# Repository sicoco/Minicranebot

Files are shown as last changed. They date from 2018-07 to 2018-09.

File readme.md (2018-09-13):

# MiniCraneBot

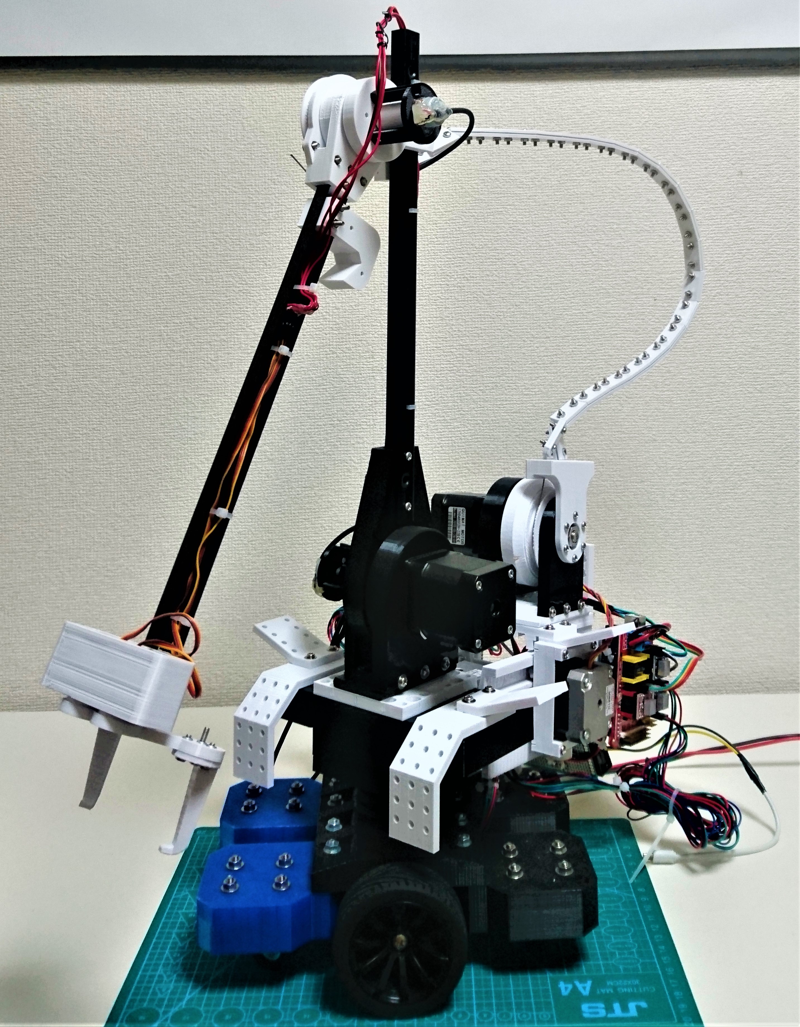
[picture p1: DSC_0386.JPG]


- basically a small mobile wheel-based platform with lightweight long robotic arm that can move around and pick things from far away without falling over.

- made most parts with 3d printer, including high gear ratio gearbox

- in order to reduce the time on prototyping and 3d printing, designed the robot's body in LEGO-ish style

- robot has 2WD and 4 caster wheel mobile platform, a 3dof planar robotic arm, 2 dof gripper, 1 dof adjustable counterweight

- able to pick about 100g at gripper and about 500g at elbow

- robot weight about 4kg because it is powered from switching power supply outside its body

[Youtube](https://www.youtube.com/watch?v=HbvBk9CqUA4)

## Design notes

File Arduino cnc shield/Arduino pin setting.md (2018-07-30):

# Arm Controller Arduino pin setting
|Arduino pin|CNC Shield V3 port Name|Connect to|Mode|
|--|--|--|--|
|D0|TX|RPi Serial|UART TX|
|D1|RX|RPi Serial|UART RX|
|D2|X-STEP|shoulder step|Accelstepper step|
|D3|Y-STEP|elbow step|Accelstepper step|
|D4|Z-STEP|waist step|Accepstepper step|
|D5|X-DIR|shoulder dir|Accelstepper dir|
|D6|Y-DIR|elbow dir|Accelstepper dir|
|D7|Z-DIR|waist dir|Accelstepper dir|
|D8|EN|All stepper driver's EN pin|Accelstepper enable|
|D9|X-Endstop|Gripper servo L|PWM|
|D10|Y-Endstop|Gripper servo R|PWM|
|D11|Z-Endstop|counterweight endstop|GPIO input|
|D12|SpnEn|counterweight step(also connects to another CNC shield's A-axis step)|Accelstepper step|
|D13|SpnDir|counterweight dir(also connects to another CNC shield's A-axis dir)|Accelstepper dir|
|A0|Abort|elbow potentiometer|ADC|
|A1|Home|shoulder potentiometer|ADC|
|A2|Resume|||
|A3|CoolEn|||
|A4|SDA|MPU6050 I2C|I2C SDA|
|A5|SCL|MPU6050 I2C|I2C SCL|

E-stop is reset button

Used libraries:
Metro: speed(25ms) and position(100ms) control
MsTimer2: get MPU6050 and potentiometer data and do some filtering to get angles updated(20ms)
Accelstepper: control all stepping motors
MPU6050_tockn: MPU605 driver
Wire: I2C library

3，5，6，9，10，11 pin have PWM function

# Car Controller Arduino pin setting
|Arduino pin|CNC Shield V3 port Name|Connect to|Mode|
|--|--|--|--|
|D0|TX|RPi Serial|UART TX|
|D1|RX|RPi Serial|UART RX|
|D2|X-STEP|Left wheel step|Accelstepper step|
|D3|Y-STEP|Right wheel step|Accelstepper step|
|D4|Z-STEP|||
|D5|X-DIR|Left wheel dir|Accelstepper dir|
|D6|Y-DIR|Right wheel dir|Accelstepper dir|
|D7|Z-DIR|||
|D8|EN|All stepper driver's EN pin(Also controls A-Axis driver's EN pin)|Accelstepper enable|
|D9|X-Endstop|||
|D10|Y-Endstop|||
|D11|Z-Endstop|||
|D12|SpnEn|should not connect to A-Axis as A-Axis driver is controlled by Arm controller Arduino now||
|D13|SpnDir|should not connect to A-Axis as A-Axis driver is controlled by Arm controller Arduino now||
|A0|Abort|||
|A1|Home|||
|A2|Resume|||
|A3|CoolEn|||
|A4|SDA|MPU6050 I2C(hopefully, if wiring can be solved)|I2C SDA|
|A5|SCL|MPU6050 I2C(hopefully, if wiring can be solved)|I2C SCL|

## Problems right now

 1. Servo are in failure: possibly overdriven too much? change new one. First print a new twin servo holder. fixed
 2. Add glue gun on gripper to increase friction. fixed
 3. Is Cooling enough? 
 4. Endstop need to get closer a little to the counterweight. fixed
 5. Why counterweight is not moving in initialization? Using runSpeed wrongly?  fixed
 6. Connect servo L and R correctly 
 7. Waist timing belt getting loose
 8. Cable entangling between car and arm. Make waist a little taller. fixed
 9. Waist plate is bending due to heavy counterweight. Make thicker waist plate.　fixed
 10. Why MPU6050_tockn not working properly? Check thoroughly.  fixed
 11. Complete feedback control on arm. fixed
 12. Elbow motor gearbox may have some problem, high friction
 13. tuning sensor offsets and servo angle offset parameters
 14. tuning Kp and error width
 15. add tensioner on waist yaw timing belt, too loose now.

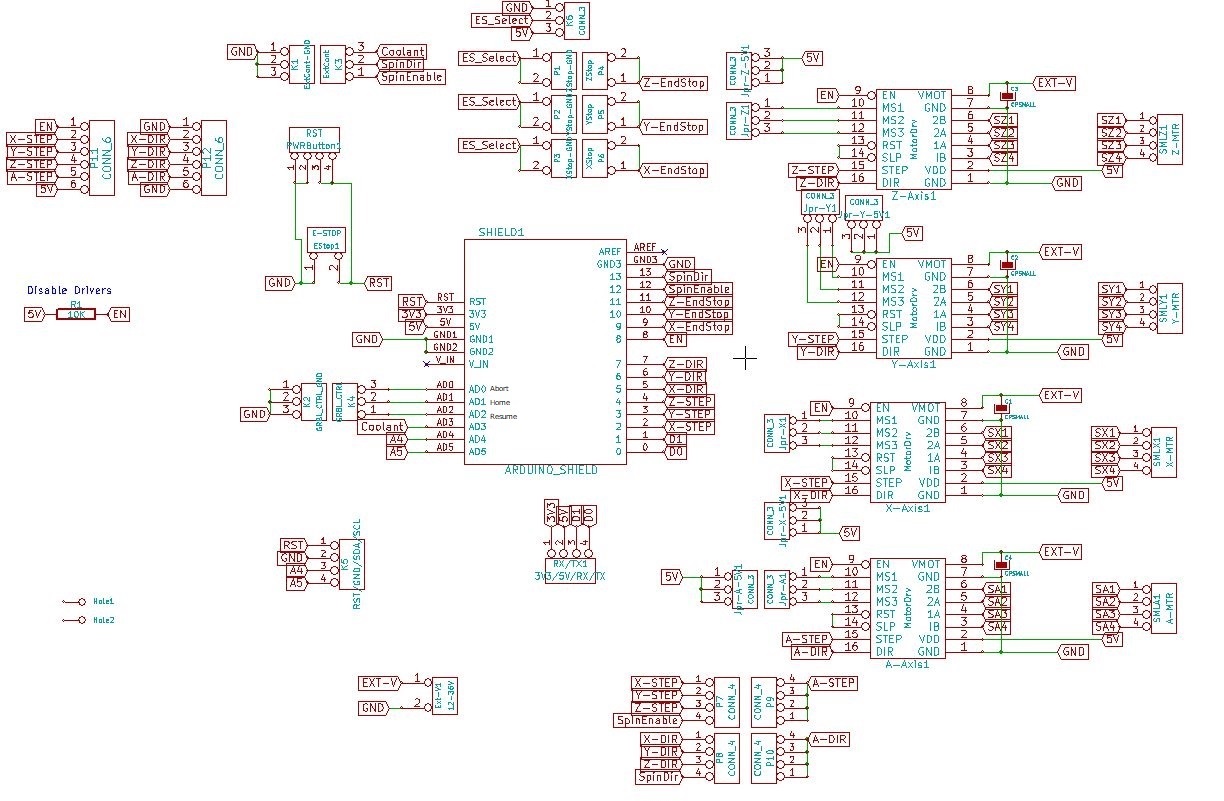
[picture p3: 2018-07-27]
Arduino cnc shield/Arduino-CNC-Shield-Scematics-V3.XX_.jpg

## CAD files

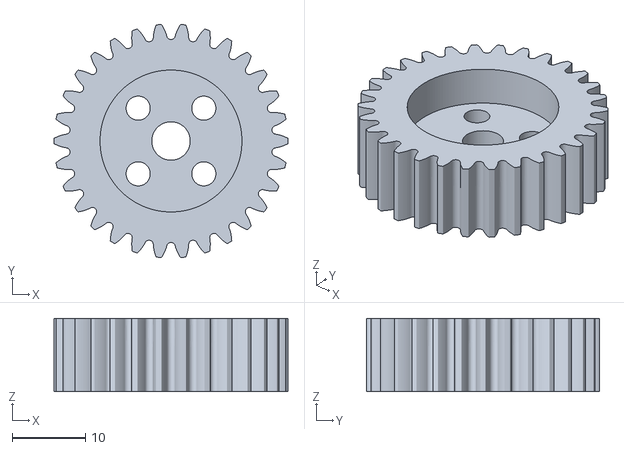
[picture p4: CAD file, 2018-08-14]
stl/30T M1 sun gear with shaft hub hole v2.stl
32.0 x 31.9 x 10.0

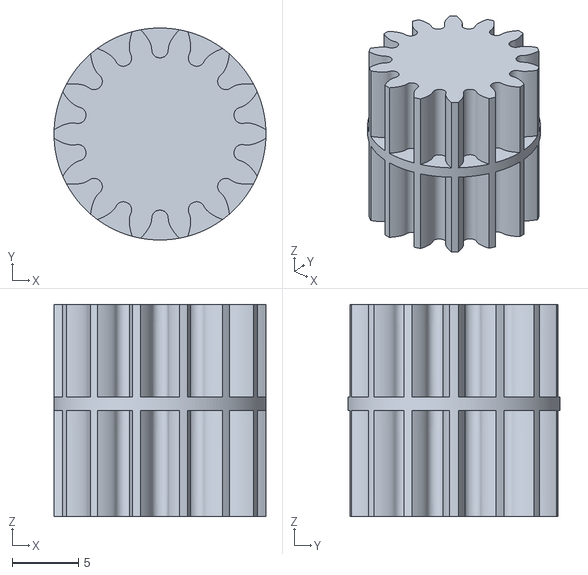
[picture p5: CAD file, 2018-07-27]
stl/planetary gear mock print at home 20180618 over night/14T planet.stl
16.0 x 16.0 x 16.0

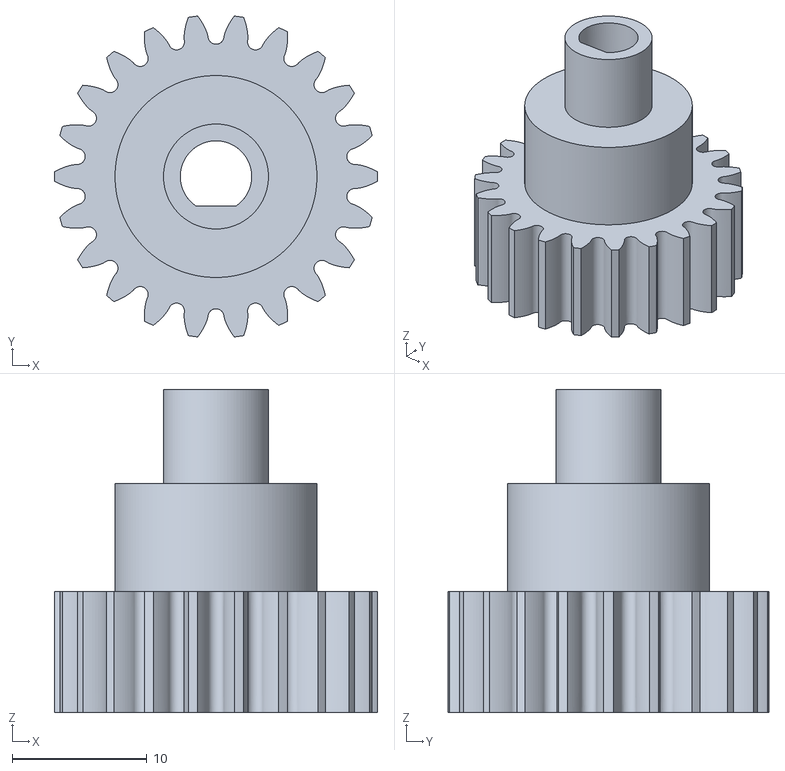
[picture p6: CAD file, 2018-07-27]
stl/planetary gearbox print at home @20180619 morning/Spur Gear (22 teeth).stl
24.0 x 23.8 x 24.0

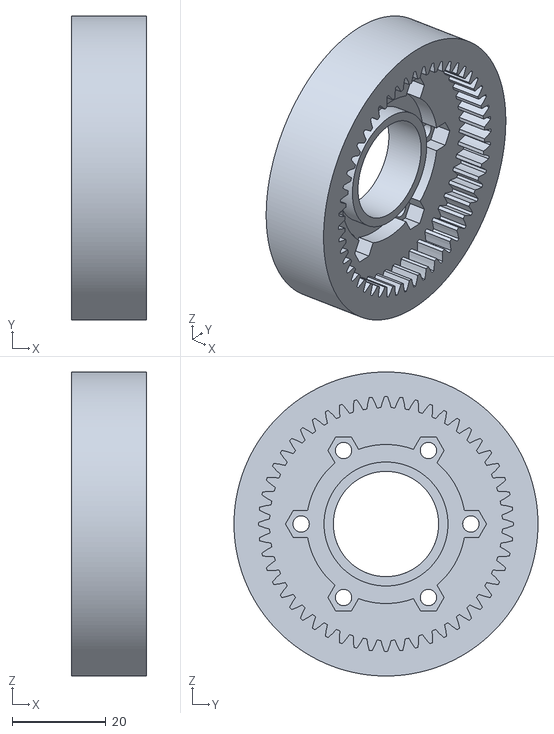
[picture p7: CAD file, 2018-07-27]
stl/Planetary gearbox print at lab 20180619/_HPC - ZIN1-52 (c).stl
16.0 x 65.0 x 65.0

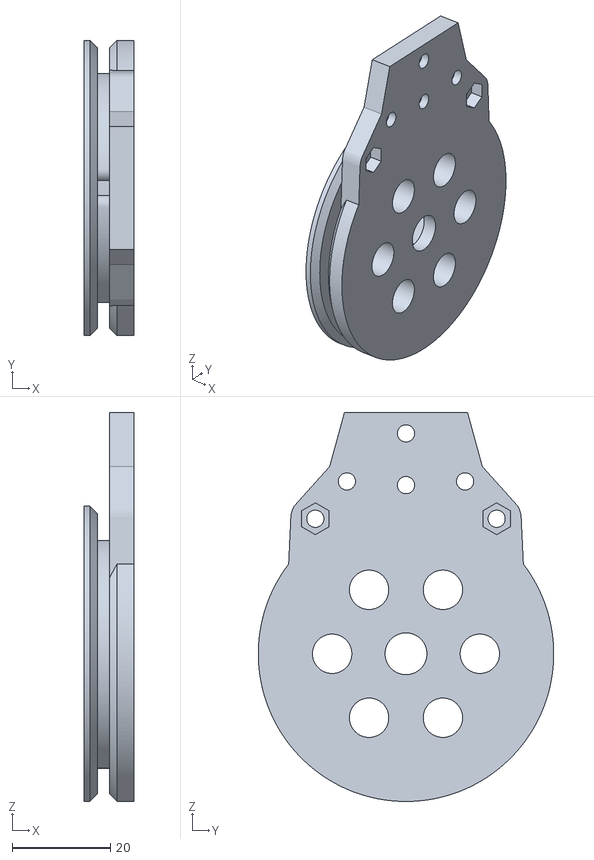
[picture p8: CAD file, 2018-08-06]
stl/bowden spool 50mm with arm v17.stl
10.2 x 60.0 x 79.0

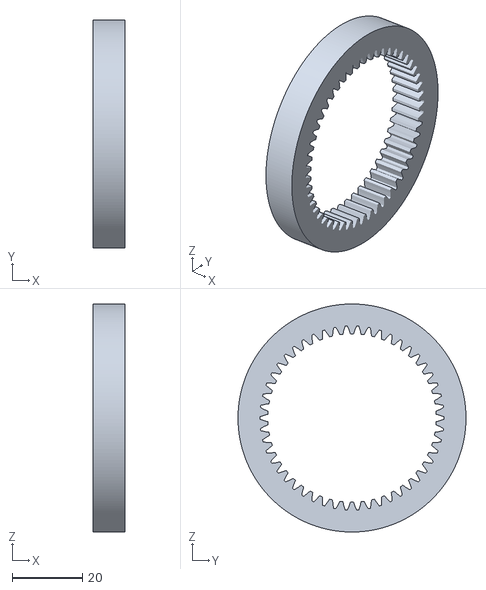
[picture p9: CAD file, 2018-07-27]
stl/planetary gear mock print at home 20180618 over night/50T internal.stl
9.00 x 65.0 x 65.0

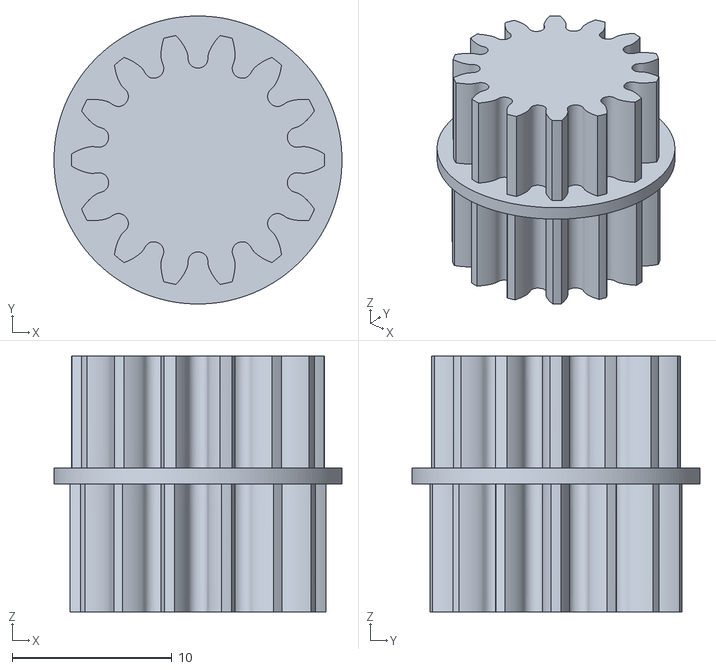
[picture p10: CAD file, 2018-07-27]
stl/planetary gearbox print at home @20180619 morning/Spur Gear (14 teeth).stl
18.0 x 18.0 x 16.0

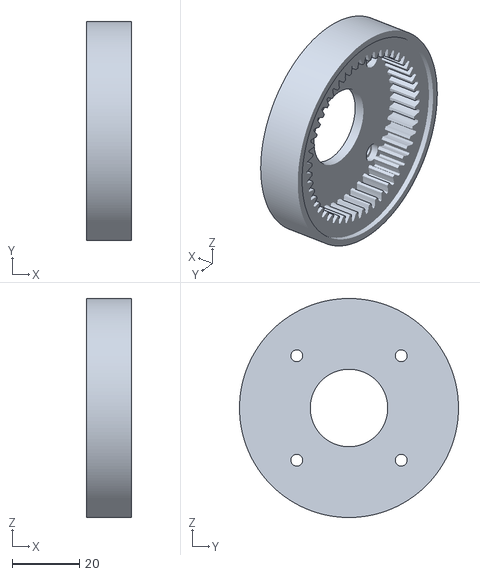
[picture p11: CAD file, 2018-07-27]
stl/Planetary gearbox print at lab 20180619/_HPC - ZIN1-50 (c).stl
13.5 x 65.0 x 65.0

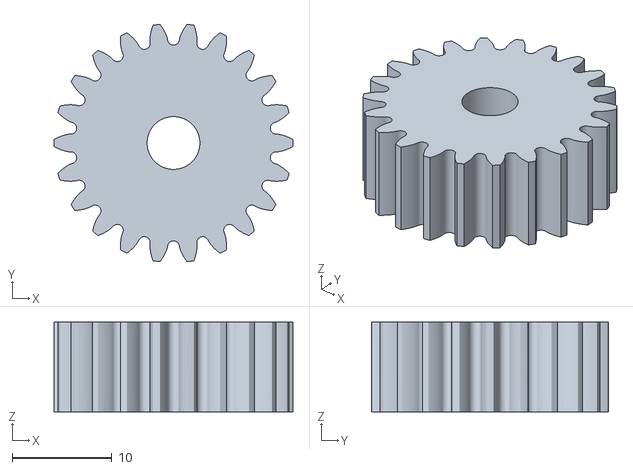
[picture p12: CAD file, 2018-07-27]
stl/planetary gear mock print at home 20180618 over night/22T sun.stl
24.0 x 23.8 x 9.00

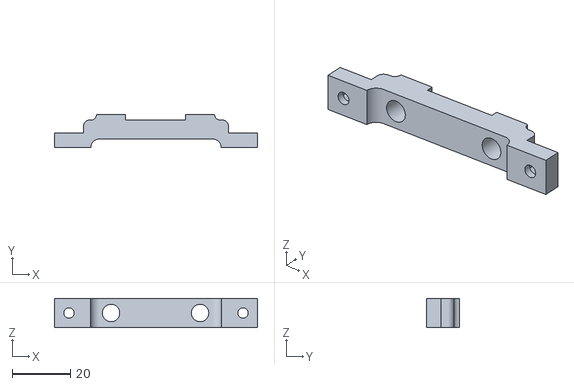
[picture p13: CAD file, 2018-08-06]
stl/tensioner plate v1.stl
70.0 x 11.5 x 10.0

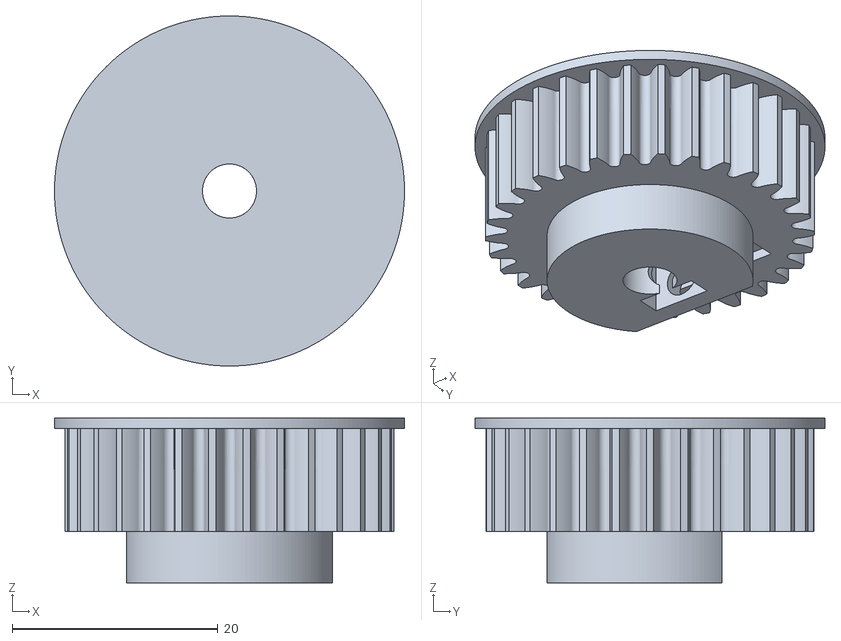
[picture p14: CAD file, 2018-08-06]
stl/30T M1 sun gear v4.stl
34.0 x 34.0 x 16.0

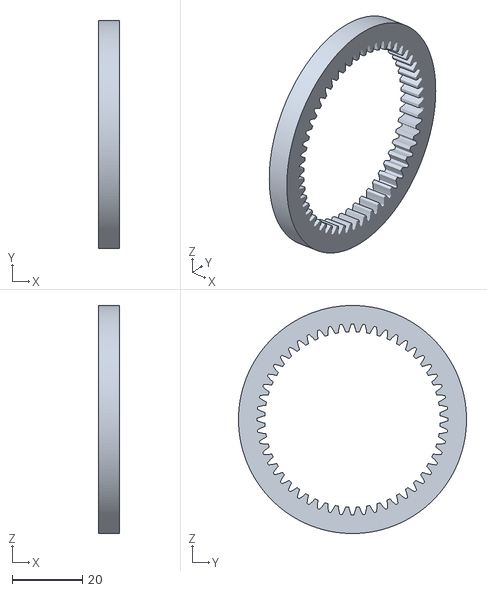
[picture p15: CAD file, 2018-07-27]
stl/planetary gear mock print at home 20180618 over night/52T internal.stl
6.00 x 65.0 x 65.0

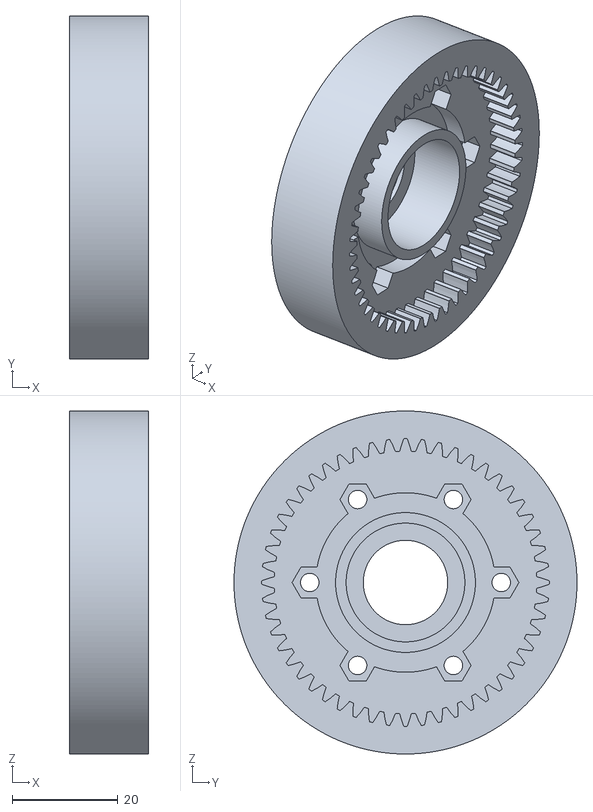
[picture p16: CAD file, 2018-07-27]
stl/planetary gearbox print at home @20180619 morning/_HPC - ZIN1-52 (c).stl
15.0 x 65.0 x 65.0

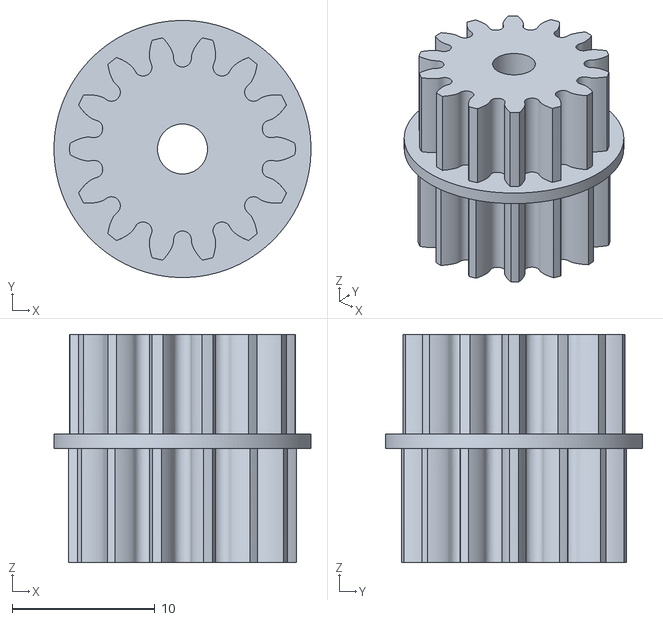
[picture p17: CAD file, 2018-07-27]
stl/Planetary gearbox print at lab 20180619/Spur Gear (14 teeth).stl
18.0 x 18.0 x 16.0

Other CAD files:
stl/wheel base.stl
stl/wedge.stl
stl/14T M1 Crossed Planet gear.stl
stl/14T M1 Planet gear.stl
stl/14T M1 Spur gear v4.stl
stl/30T M1 sun gear.stl
stl/42 stepper motor fixture spacer 2mm.stl
stl/52T enhanced.stl
stl/58T M1 Internal Gear.stl
stl/60T M1 Internal Gear Bowden_60T M1 Internal Gear Bowden v7_Body1_60T M1 Internal Gear.stl
stl/60T M1 Internal Gear Bowden_planetary gearbox bowden cable actuator v9_spool_1_Body1_spool.stl
stl/60T M1 Internal Gear.stl
stl/Body1.stl
stl/Body2.stl
stl/GT2 70T timingpulley v23_base chassis another plan 4 v76_pulley_1_Body1_.stl
stl/GT2 70T timingpulley v23_base chassis another plan 4 v76_pulley_1_pulley cap_1_Body1_pulley cap.stl
stl/GT2 70T timingpulley v23_base chassis foldable bridge form rough sketch v9_pulley_1_Body1_.stl
stl/GT2 70T timingpulley v23_base chassis foldable bridge form rough sketch v9_pulley_1_pulley cap_1_Body1_pulley cap.stl
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

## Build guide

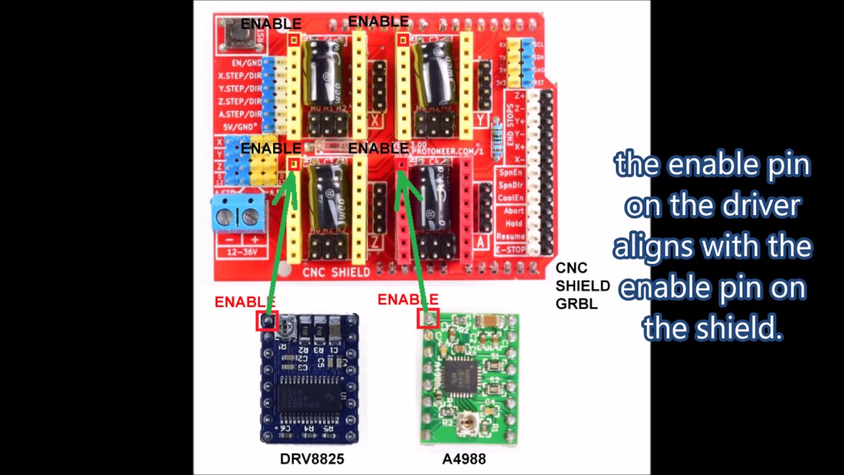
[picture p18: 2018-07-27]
Arduino cnc shield/CNC shield wiring.jpg

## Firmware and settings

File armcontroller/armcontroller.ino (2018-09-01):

#include "MPU6050_tockn.h"
#include <Wire.h>
#include <MsTimer2.h>
#include <AccelStepper.h>
#include <Metro.h>
#include <Servo.h>

#define DEVICE_NAME "Arm"

#define DEFAULT_ELBOW_ANGLE 135
#define DEFAULT_SHOULDER_ANGLE 110
#define DEFAULT_WAIST_YAW_ANGLE 0
#define DEFAULT_GRIPPER_L_ANGLE 125
#define DEFAULT_GRIPPER_R_ANGLE 55

//Arm Control
//Includes waist, shoulder, elbow, counterweight stepper and gripper servos and IMU@arm

String inputString = "";
boolean stringComplete = false;

MPU6050 mpu6050(Wire);

// Define steppers and the pins it will use
AccelStepper shoulderstepper(1, 2, 5);//X-axis DRV8825 Full step
AccelStepper elbowstepper(1, 3, 6); //Y-axis DRV8825 Full step
AccelStepper waistyawstepper(1, 4, 7); //Z-axis A4988  8 microstep
AccelStepper counterweightstepper(1, 12, 13); //A-axis A4988 * 2 8 microstep
Servo gripper_L;
Servo gripper_R;
const int servogripper_L_pin = 9; //X-endstop
const int servogripper_R_pin = 10; //Y-endstop
const int elbow_potentiometer_pin = A0; //Abort
const int shoulder_potentiometer_pin = A1; //Hold
const int counterweight_endstop_pin = 11;//Z-endstop

const int max_shoulder_sp = 600;
const int max_elbow_sp = 500;
const int max_waist_yaw_sp = 1000;
const int max_counterweight_sp = 1000;



Metro spcontrolMetro = Metro(50);//50ms
Metro reportMetro = Metro(1000);//1000ms

int set_waist_yaw_sp;
int set_elbow_sp;
int set_shoulder_sp;

int waist_yaw_sp;
int elbow_sp;
int shoulder_sp;

int waist_yaw_sp_diff;
int elbow_sp_diff;
int shoulder_sp_diff;

int waist_yaw_acc = 100;
int elbow_acc = 100;
int shoulder_acc = 20;

float filter_a = 0.3;

float current_elbow_value;
float current_shoulder_value;
int current_elbow_angle;
int current_shoulder_angle;
int current_waist_yaw_angle;
int current_waist_pitch_angle;
//int current_counterweight_position = 0;

float shoulder_effectivity;
float elbow_effectivity;
float shoulder_stall_threshold = 1000;
float elbow_stall_threshold = 4000;

int set_elbow_angle = DEFAULT_ELBOW_ANGLE;
int set_shoulder_angle = DEFAULT_SHOULDER_ANGLE;
int set_waist_yaw_angle = DEFAULT_WAIST_YAW_ANGLE;
int set_counterweight_position = 0;

int set_gripper_L = DEFAULT_GRIPPER_L_ANGLE;
int set_gripper_R = DEFAULT_GRIPPER_R_ANGLE;

const int max_elbow_angle = 175;
const int min_elbow_angle = 0;
const int max_shoulder_angle = 190;
const int min_shoulder_angle = 75;
const int max_waist_yaw_angle = 180;
const int min_waist_yaw_angle = -180;
const int max_counterweight_range = 45 / 2 / PI / 7 * 8 * 200; //pulses for 47mm range of motion
const int min_counterweight_range = 0;

const int max_gripper_angle = 180;
const int min_gripper_angle = 0;
const int gripper_L_offset = 5;
const int gripper_R_offset = 5;

const int elbow_offset = -110;
const int shoulder_offset = -20;
//const int waist_yaw_offset = 0;
int offset_yaw = 0;
int offset_pitch = 0;

int error_shoulder;
int error_elbow;
float error_waist_yaw;
float error_waist_pitch;

int compensation_waist_pitch;

int kp_elbow = 40;
int kp_shoulder = 40;
int kp_waist_yaw = 50;
int kp_waist_pitch = 50;

int error_width_elbow = 2;
int error_width_shoulder = 1;
int error_width_waist_yaw = 1;
float error_width_waist_pitch = 0.2;

//const int upper_arm_length = 280;
//const int lower_arm_length = 386;//include gripper length
//Position setpoint = {100, 0, 0};
//Position currentpoint;
//float pos_allow_error_half_width = 10;

void setup()
{
  inputString.reserve(60);
  Serial.begin(115200);

  shoulderstepper.setEnablePin(8);
  shoulderstepper.setPinsInverted(false, false, true);
  shoulderstepper.setMaxSpeed(max_shoulder_sp);
  shoulderstepper.setAcceleration(1000);
  shoulderstepper.enableOutputs();

  elbowstepper.setEnablePin(8);
  elbowstepper.setPinsInverted(false, false, true);
  elbowstepper.setMaxSpeed(max_elbow_sp);
  elbowstepper.setAcceleration(1000);
  elbowstepper.enableOutputs();

  waistyawstepper.setEnablePin(8);
  waistyawstepper.setPinsInverted(false, false, true);
  waistyawstepper.setMaxSpeed(max_waist_yaw_sp);
  waistyawstepper.setAcceleration(50);
  waistyawstepper.enableOutputs();

  counterweightstepper.setEnablePin(8);
  counterweightstepper.setPinsInverted(false, false, true);
  counterweightstepper.setMaxSpeed(max_counterweight_sp);
  counterweightstepper.setAcceleration(1000);
  counterweightstepper.enableOutputs();

  pinMode(counterweight_endstop_pin, INPUT);
  gripper_L.attach(servogripper_L_pin);
  gripper_R.attach(servogripper_R_pin);
  gripper_L.write(set_gripper_L);
  gripper_R.write(set_gripper_R);
  //  Serial.println(F("Counterweight reset position"));
  resetCounterweightPosition();
  //  Serial.println(F("Counterweight reset done"));
  Wire.begin();
  Wire.setClock(100000);
  mpu6050.begin();
  mpu6050.calcGyroOffsets(false);
  offset_pitch = mpu6050.getAngleY();
  //mpu6050.setGyroOffsets(-1.57,1.87,-0.31);
  MsTimer2::set(40, getAngle); // 40ms period
  MsTimer2::start();
  delay(1000);
}

void getAngle()
{
  sei();
  mpu6050.update();
  current_elbow_value = (1 - filter_a) * current_elbow_value + filter_a * analogRead(elbow_potentiometer_pin);
  current_shoulder_value = (1 - filter_a) * current_shoulder_value + filter_a * analogRead(shoulder_potentiometer_pin);
  current_elbow_angle = map(current_elbow_value, 0, 1023, 0, 335) + elbow_offset;
  current_shoulder_angle = map(current_shoulder_value, 0, 1023, 330, 0) + shoulder_offset;

  current_waist_yaw_angle = mpu6050.getAngleZ() + offset_yaw;
  current_waist_pitch_angle = mpu6050.getAngleY() - offset_pitch;
  //  current_counterweight_position = counterweightstepper.currentPosition();
}

//void calccurPos()
//{
//  float radb = (current_elbow_angle + current_shoulder_angle) / 180 * PI;
//  float rada = current_shoulder_angle / 180 * PI;
//
//  currentpoint = {lower_arm_length * cos(radb) + upper_arm_length * cos(rada), 0, lower_arm_length * sin(radb) + upper_arm_length * sin(rada)};
//}
//Position posdiff()
//{
//  return {setpoint.x - currentpoint.x, setpoint.y - currentpoint.y, setpoint.z - currentpoint.z};
//}
void loop()
{
  if (spcontrolMetro.check() == 1)  //50ms
  {
    set_gripper_L = constrain(set_gripper_L, min_gripper_angle + gripper_L_offset, max_gripper_angle + gripper_L_offset);
    set_gripper_R = constrain(set_gripper_R, min_gripper_angle + gripper_R_offset, max_gripper_angle + gripper_R_offset);
    gripper_L.write(set_gripper_L);
    gripper_R.write(set_gripper_R);

    error_shoulder = set_shoulder_angle - current_shoulder_angle;
    error_elbow = set_elbow_angle - current_elbow_angle;
    error_waist_yaw = set_waist_yaw_angle - current_waist_yaw_angle;
    error_waist_pitch = -current_waist_pitch_angle;

    if (abs(error_shoulder) > error_width_shoulder)
    {
      set_shoulder_sp = error_shoulder * kp_shoulder;
    }
    else
    {
      set_shoulder_sp = 0;
    }
    if (abs(error_elbow) > error_width_elbow)
    {
      set_elbow_sp = error_elbow * kp_elbow;
    }
    else
    {
      set_elbow_sp = 0;
    }
    if (abs(error_waist_yaw) > error_width_waist_yaw)
    {
      set_waist_yaw_sp = error_waist_yaw * kp_waist_yaw;
    }
    else
    {
      set_waist_yaw_sp = 0;
    }
    if (abs(error_waist_pitch) >= error_width_waist_pitch)
    {
      compensation_waist_pitch = error_waist_pitch * kp_waist_pitch;
    }
    else
    {
      compensation_waist_pitch = 0;
    }

    set_waist_yaw_sp = constrain(set_waist_yaw_sp, -max_waist_yaw_sp, max_waist_yaw_sp);
    set_shoulder_sp = constrain(set_shoulder_sp, -max_shoulder_sp, max_shoulder_sp);
    set_elbow_sp = constrain(set_elbow_sp, -max_elbow_sp, max_shoulder_sp);

    waist_yaw_sp_diff = set_waist_yaw_sp - waist_yaw_sp;
    shoulder_sp_diff = set_shoulder_sp - shoulder_sp;
    elbow_sp_diff = set_elbow_sp - elbow_sp;

    if (waist_yaw_sp_diff > waist_yaw_acc)
    {
      waist_yaw_sp += waist_yaw_acc;
    }
    else if (waist_yaw_sp_diff < (-1)*waist_yaw_acc)
    {
      waist_yaw_sp -= waist_yaw_acc;
    }
    else
    {
      waist_yaw_sp = set_waist_yaw_sp;
    }

    if (shoulder_sp_diff > shoulder_acc)
    {
      shoulder_sp += shoulder_acc;
    }
    else if (shoulder_sp_diff < (-1)*shoulder_acc)
    {
      shoulder_sp -= shoulder_acc;
    }
    else
    {
      shoulder_sp = set_shoulder_sp;
    }

    if (elbow_sp_diff > elbow_acc)
    {
      elbow_sp += elbow_acc;
    }
    else if (elbow_sp_diff < (-1)*elbow_acc)
    {
      elbow_sp -= elbow_acc;
    }
    else
    {
      elbow_sp = set_elbow_sp;
    }

    //    if (counterweightstepper.targetPosition() -  compensation_waist_pitch >= max_counterweight_range)
    //    {
    //      counterweightstepper.moveTo(max_counterweight_range);
    //    }
    //    else if (counterweightstepper.targetPosition() -  compensation_waist_pitch <= min_counterweight_range)
    //    {
    //      counterweightstepper.moveTo(min_counterweight_range);
    //    }
    //    else
    //    {
    //      counterweightstepper.move(compensation_waist_pitch);
    //    }
    set_counterweight_position -= compensation_waist_pitch;
    set_counterweight_position = constrain(set_counterweight_position, min_counterweight_range, max_counterweight_range);
    counterweightstepper.moveTo(-set_counterweight_position);
    Serial.println(set_counterweight_position);

    shoulderstepper.setSpeed(-shoulder_sp);
    elbowstepper.setSpeed(elbow_sp);
    waistyawstepper.setSpeed(waist_yaw_sp);
  }

  //  if (reportMetro.check() == 1) //1sec
  //  {
  //        Serial.print(current_shoulder_angle);
  //        Serial.print("->");
  //        Serial.print(set_shoulder_angle);
  //        Serial.print("(");
  //        Serial.print(set_shoulder_sp);
  //        Serial.print(") ");
  //        Serial.print(current_elbow_angle);
  //        Serial.print("->");
  //        Serial.print(set_elbow_angle);
  //        Serial.print("(");
  //        Serial.print(set_elbow_sp);
  //        Serial.print(") ");
  //        Serial.print(current_waist_yaw_angle);
  //        Serial.print("->");
  //        Serial.print(set_waist_yaw_angle);
  //        Serial.print("(");
  //        Serial.print(set_waist_yaw_sp);
  //        Serial.print(") ");
  //        Serial.print(current_waist_pitch_angle);
  //        Serial.print("(");
  //        Serial.print(counterweightstepper.targetPosition());
  //        Serial.println(")");
  //  }

  if (stringComplete)
  {
    int arg1, arg2, arg3, arg4, arg5;
    if (sscanf(inputString.c_str(), "A%d %d %d %d %d", &arg1, &arg2, &arg3, &arg4, &arg5) == 5)
    {
      set_shoulder_angle = arg1;
      set_elbow_angle = arg2;
      set_waist_yaw_angle = arg3;
      set_gripper_L = arg4;
      set_gripper_R = arg5;
    }
    else if (sscanf(inputString.c_str(), "A%d %d %d", &arg1, &arg2, &arg3) == 3)
    {
      set_shoulder_angle = arg1;
      set_elbow_angle = arg2;
      set_waist_yaw_angle = arg3;
    }
    else if (sscanf(inputString.c_str(), "G%d %d", &arg4, &arg5) == 2)
    {
      set_gripper_L = arg4;
      set_gripper_R = arg5;
    }
    else if (sscanf(inputString.c_str(), "F%d", &arg1) == 1)
    {
      offset_yaw = arg1;
    }
    else if (inputString == "name?")
    {
      Serial.println(DEVICE_NAME);
    }
    else if (inputString == "pwroff")//motor power off
    {
      elbowstepper.disableOutputs();
    }
    else if (inputString == "pwron")//motor power on
    {
      elbowstepper.enableOutputs();
    }
    else if (inputString == "psrst")//reset pose
    {
      //      resetCounterweightPosition();
      set_gripper_L = DEFAULT_GRIPPER_L_ANGLE + gripper_L_offset;
      set_gripper_R = DEFAULT_GRIPPER_R_ANGLE + gripper_R_offset;
      set_elbow_angle = DEFAULT_ELBOW_ANGLE;
      set_shoulder_angle = DEFAULT_SHOULDER_ANGLE;
      set_waist_yaw_angle = DEFAULT_WAIST_YAW_ANGLE;
      // Serial.println("Done");
    }
    else if (inputString == "st") //report current angle status
    {
      Serial.print(current_shoulder_angle);
      Serial.print(" ");
      Serial.print(current_elbow_angle);
      Serial.print(" ");
      Serial.println(current_waist_yaw_angle);
    }
    //    else if (inputString == "w")
    //    {
    //      elbowstepper.move(500);
    //    }
    //    else if (inputString == "s")
    //    {
    //      elbowstepper.move(-500);
    //    }
    //    else if (inputString == "a")
    //    {
    //      shoulderstepper.move(500);
    //    }
    //    else if (inputString == "d")
    //    {
    //      shoulderstepper.move(-500);
    //    }
    //    else if (inputString == "z")
    //    {
    //      waistyawstepper.move(1000);
    //    }
    //    else if (inputString == "x")
    //    {
    //      waistyawstepper.move(-1000);
    //    }
    //    else if (inputString == "c")
    //    {
    //      counterweightstepper.move(1000);
    //      if (counterweightstepper.targetPosition() > max_counterweight_range)
    //      {
    //        counterweightstepper.moveTo(max_counterweight_range);
    //      }
    //    }
    //    else if (inputString == "v")
    //    {
    //      counterweightstepper.move(-1000);
    //      if (counterweightstepper.targetPosition() < min_counterweight_range)
    //      {
    //        counterweightstepper.moveTo(min_counterweight_range);
    //      }
    //    }
    //    else if (inputString == "t")
    //    {
    //      set_gripper_L += 10;
    //    }
    //    else if (inputString == "g")
    //    {
    //      set_gripper_L -= 10;
    //    }
    //    else if (inputString == "y")
    //    {
    //      set_gripper_R += 10;
    //    }
    //    else if (inputString == "h")
    //    {
    //      set_gripper_R -= 10;
    //    }
    else //received any illegal message, stop the motion
    {

      set_elbow_angle = current_elbow_angle;
      set_shoulder_angle = current_shoulder_angle;
      set_waist_yaw_angle = current_waist_yaw_angle;
      //  set_counterweight_position =  current_counterweight_position;
    }

    set_elbow_angle = constrain(set_elbow_angle, min_elbow_angle, max_elbow_angle);
    set_shoulder_angle = constrain(set_shoulder_angle, min_shoulder_angle, max_shoulder_angle);
    set_waist_yaw_angle = constrain(set_waist_yaw_angle, min_waist_yaw_angle, max_waist_yaw_angle);

    stringComplete = false;
    inputString = "";
  }


  shoulderstepper.runSpeed();
  elbowstepper.runSpeed();
  waistyawstepper.runSpeed();
  counterweightstepper.run();

  //  if (!digitalRead(counterweight_endstop_pin))
  //  {
  //    counterweightstepper.setCurrentPosition(min_counterweight_range);
  //  }
}
void serialEvent()
{
  while (Serial.available())
  {
    char c = (char)Serial.read();
    if (c == '\n' || c == '\r') {
      stringComplete = true;
    }
    else {
      inputString += c;
    }
  }
}

void resetCounterweightPosition()
{
  while (digitalRead(counterweight_endstop_pin))
  {

    digitalWrite(13, HIGH);
    digitalWrite(12, HIGH);
    delay(2);
    digitalWrite(12, LOW);
  }
  delay(500);
  for (int i = 0 ; i < max_counterweight_range / 2; i++)  //go to midpoint of the counterweight range
  {
    digitalWrite(13, LOW);
    digitalWrite(12, HIGH);
    delay(2);
    digitalWrite(12, LOW);
  }
  counterweightstepper.setCurrentPosition(-max_counterweight_range / 2);

}

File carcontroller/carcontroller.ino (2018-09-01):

#include <MsTimer2.h>
#include "MPU6050_tockn.h"
#include <Wire.h>
#include <AccelStepper.h>
#include <Metro.h>

#define DEVICE_NAME "Car"

//Car Control
//Includes left and right wheel stepper and IMU for yaw compensation

MPU6050 mpu6050(Wire);

String inputString = "";
boolean stringComplete = false;

// Define steppers and the pins it will use
AccelStepper leftstepper(1, 2, 5);//X-axis DRV8825 8 microstep
AccelStepper rightstepper(1, 3, 6); //Y-axis DRV8825 8 microstep

const int max_sp = 1000;

Metro spcontrolMetro = Metro(50);//50ms

int left_sp;
int right_sp;

int set_left_speed = 0;
int set_right_speed = 0;
int set_speed = 0;
int acceleration = 100;
boolean rotation = false;

volatile float current_yaw = 0;
float set_yaw = 0;
float yaw_error_width = 2.0;
float kp = 20.0;
float offset_yaw = 0;
void setup()
{
  inputString.reserve(60);
  Serial.begin(115200);
  // Change these to suit your stepper if you want
  leftstepper.setEnablePin(8);
  leftstepper.setPinsInverted(false, false, true);
  leftstepper.setMaxSpeed(max_sp);
  leftstepper.setAcceleration(300);
  leftstepper.enableOutputs();

  rightstepper.setEnablePin(8);
  rightstepper.setPinsInverted(false, false, true);
  rightstepper.setMaxSpeed(max_sp);
  rightstepper.setAcceleration(300);
  rightstepper.enableOutputs();
  delay(5000);
  Wire.begin();
  Wire.setClock(100000);
  mpu6050.begin();
  mpu6050.calcGyroOffsets(false);
  //mpu6050.setGyroOffsets(-2.14,-2.60,-2.36);
  
  MsTimer2::set(20, getAngle); // 20ms period
  MsTimer2::start();
}

void getAngle()
{
  sei();
  mpu6050.update();
  current_yaw = mpu6050.getAngleZ() + offset_yaw;
}

void loop()
{
  if (spcontrolMetro.check() == 1)
  {
    //    mpu6050.update();
    float error = set_yaw - current_yaw;
    float speed_compensation = 0;
    if (error > yaw_error_width || error < -yaw_error_width) //need compensation for yaw angle;
    {
      speed_compensation = error * kp;
    }
    if (!rotation)
    {
      set_left_speed = set_speed;
      set_right_speed = set_speed;
    }
    else
    {

      set_left_speed = set_speed;
      set_right_speed = (-1) * set_speed;

    }

    set_left_speed -= speed_compensation;
    set_right_speed += speed_compensation;

    int left_sp_diff = set_left_speed - left_sp;
    int right_sp_diff = set_right_speed - right_sp;

    if (left_sp_diff > acceleration)
    {
      left_sp += acceleration;
    }
    else if (left_sp_diff < (-1)*acceleration)
    {
      left_sp -= acceleration;
    }
    else
    {
      left_sp = set_left_speed;
    }

    if (right_sp_diff > acceleration)
    {
      right_sp += acceleration;
    }
    else if (right_sp_diff < (-1)*acceleration)
    {
      right_sp -= acceleration;
    }
    else
    {
      right_sp = set_right_speed;
    }

    leftstepper.setSpeed(left_sp);
    rightstepper.setSpeed(right_sp);
  }
  if (stringComplete)
  {
    int argyaw;
    int argsp;
    if (sscanf(inputString.c_str(), "T%d", &argsp) == 1)//go forward or backward at certain speed. Yaw compensation will keep the same yaw angle while running
    {
      set_yaw = current_yaw;
      if (argsp < max_sp && argsp > (-1) * max_sp)
      {
        set_speed = argsp;
      }
      else if (argsp >= max_sp)
      {
        set_speed = max_sp;
      }
      else if (argsp <= (-1) * max_sp)
      {
        set_speed = (-1) * max_sp;
      }
      rotation = false;
    }
    else if (sscanf(inputString.c_str(), "R%d %d", &argyaw, &argsp) == 2)//rotate with certain speed
    {
      set_yaw += (float)argyaw;
      if (argsp < max_sp && argsp > (-1) * max_sp)
      {
        set_speed = argsp;
      }
      else if (argsp >= max_sp)
      {
        set_speed = max_sp;
      }
      else if (argsp <= (-1) * max_sp)
      {
        set_speed = (-1) * max_sp;
      }
      rotation = true;
    }
    else if (sscanf(inputString.c_str(), "F%d", &argyaw) == 1) //set yaw offset, because gyro will drift over time
    {
      offset_yaw = (float)argyaw;
    }
    else if (inputString == "name?")
    {
      Serial.println(DEVICE_NAME);
    }
    else if (inputString == "pwroff")
    {
      leftstepper.disableOutputs();
    }
    else if (inputString == "pwron")
    {
      leftstepper.enableOutputs();
    }
    else if (inputString == "st")
    {
      Serial.println((int)current_yaw);
    }
    else //received any illegal message, stop the motion
    {
      set_yaw = current_yaw;
      set_speed = 0;
      rotation = false;
    }

    stringComplete = false;
    inputString = "";
  }

  leftstepper.runSpeed();
  rightstepper.runSpeed();
}
void serialEvent()
{
  while (Serial.available())
  {
    char c = (char)Serial.read();
    if (c == '\n' || c == '\r') {
      stringComplete = true;
    }
    else {
      inputString += c;
    }
  }
}

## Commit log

2018-07-27 added cad model and pin setting notes
    [14T M1 Crossed Planet gear.stl, 14T M1 Planet gear.stl, 14T M1 Spur gear v4.stl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]
2018-07-28 added yaw compensation for car control
    also put two MPU6050_tockn in car and arm controller as they need to read different data from sensor
2018-07-29 added shoulder, elbow, waist yaw feedback control
2018-07-30 updated notes
    [wedge v2.stl, wedge.stl]
2018-08-02 calibrating sensor values
2018-08-02 comment out some println
2018-08-06 more steady mpu6050 reading by timer
    [30T M1 sun gear v4.stl, bowden spool 50mm with arm v17.stl, gt2 70tbase.stl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]
2018-08-14 added processing sketch
    [30T M1 sun gear with shaft hub hole v2.stl]
